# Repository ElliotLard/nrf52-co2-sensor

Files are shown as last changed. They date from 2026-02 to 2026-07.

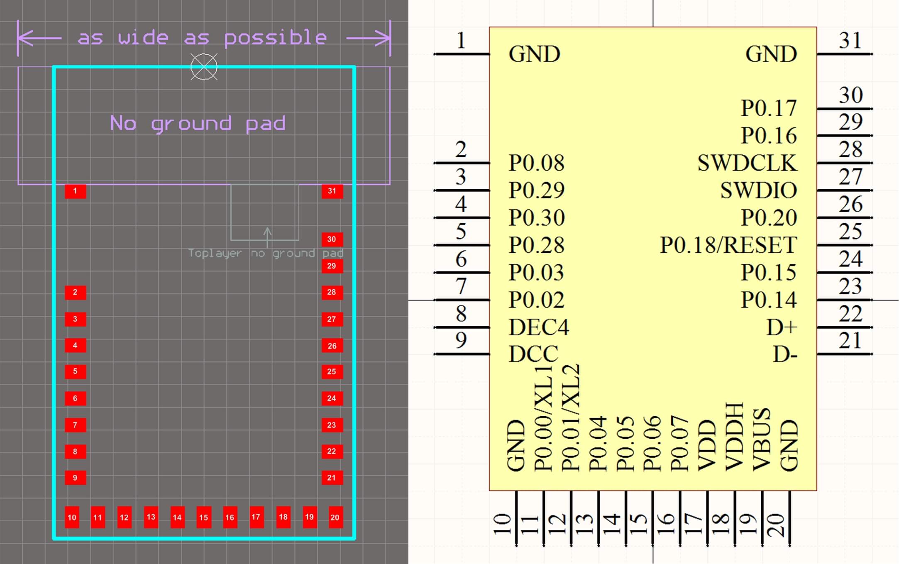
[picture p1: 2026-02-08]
hardware/datasheets/MDBT50 & MDBT50-P Footprint & Design Guide (221129)/Footprint (nRF52820)_MDBT50-256R & P256R/MDBT50 Altium Library/MDBT50_52820 Altium Library-210706.jpg

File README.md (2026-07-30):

# nrf52-co2-sensor





BLE-based smart home compatible CO₂ sensor built around the **nRF52840 (via MDBT50Q module)** and the **Sensirion SCD30 NDIR CO₂ sensor**.

The device measures indoor CO₂ concentration and transmits readings wirelessly using **Bluetooth Low Energy (BLE)** for integration with smart home systems or mobile applications.

This project includes:

- Custom **schematic design**
- **PCB layout** in KiCad
- **BLE communication**
- Sensor integration using **I²C**

---

# Project Status

**Current Status (30 July 2026)**
- Rev A Board has been printed and assembled
---
#Front


#Back


# Hardware Design

## Schematic (Rev A)



## PCB Layout (Rev A)



---

# Design Goals

- Accurate CO₂ measurement
- Wireless communication via **Bluetooth Low Energy**
- USB-C powered device
- Smart home compatibility

---

# Major Components

## MCU + BLE

**MDBT50Q-1MV2**  
Contains **Nordic nRF52840 BLE microcontroller**



---

## CO₂ Sensor

**Sensirion SCD30**

NDIR-based CO₂ sensor with integrated temperature and humidity measurement.



---

## USB-C Receptacle

**USB4105-GF-A**

Used for power and optional USB communication/debugging.



---

<!---
Future updates:

- Rev B schematic
- PCB layout screenshots
- Fabricated board photos

---
-->
# Firmware

*(Placeholder — firmware development will begin after PCB assembly)*

Planned features:

- I²C communication with SCD30
- CO₂ measurement acquisition
- BLE data transmission
- Low power operation

---

# Tools Used

- **KiCad** — schematic and PCB design
- **Git / GitHub** — version control
- **Datasheets and reference designs** from component manufacturers

---

# Future Work

- BLE data integration with **Home Assistant**
- Explore possibility of Battery-powered variant
- Compact enclosure design
- Airflow optimization for accurate sensing

---

<!---
# License

*(Placeholder — consider adding MIT or Apache license)*
-->

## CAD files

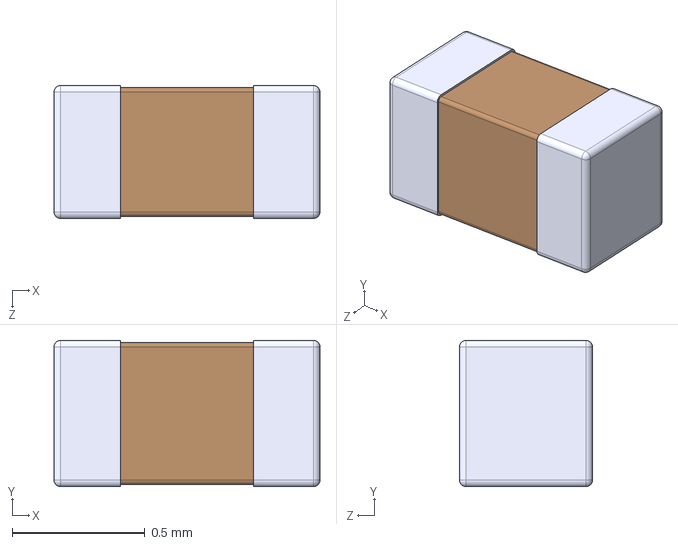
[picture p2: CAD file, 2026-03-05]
hardware/BLM15AX601SN1D (Ferrite Bead)/BEADC1005X55N.step
1.00 x 0.55 x 0.5 mm

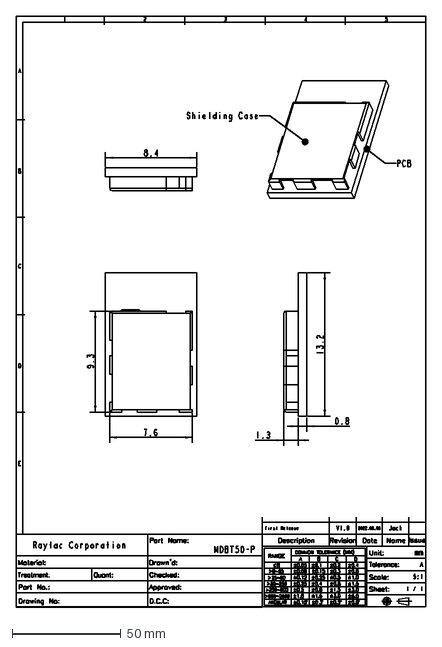
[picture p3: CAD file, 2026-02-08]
hardware/datasheets/MDBT50 & MDBT50-P Footprint & Design Guide (221129)/2D & 3D Drawing/MDBT50-P/2D/MDBT50-P 2D Drawing_20221129.dxf
188.5 x 271.9 mm

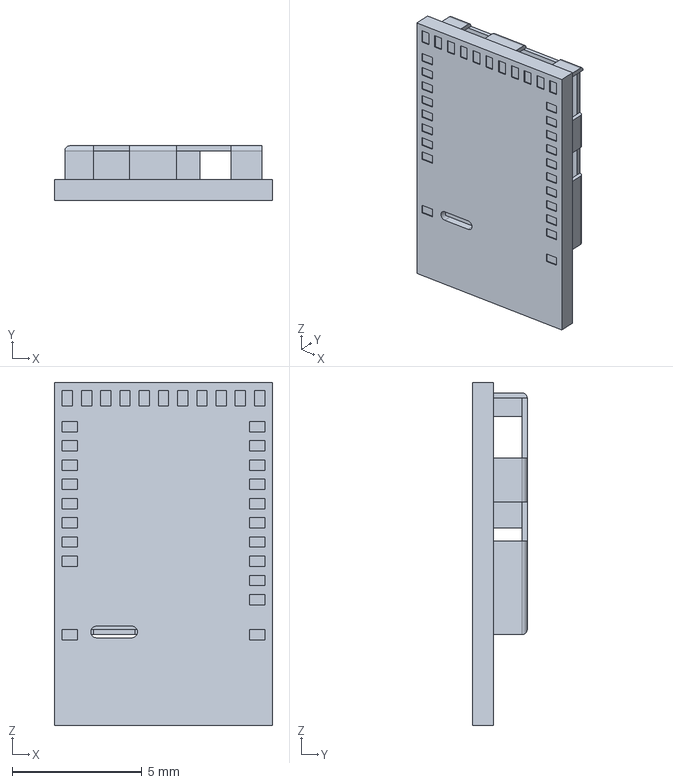
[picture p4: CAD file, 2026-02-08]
hardware/datasheets/MDBT50 & MDBT50-P Footprint & Design Guide (221129)/2D & 3D Drawing/MDBT50-P/3D/MDBT50-P_220606.stp
8.40 x 2.10 x 13.2 mm

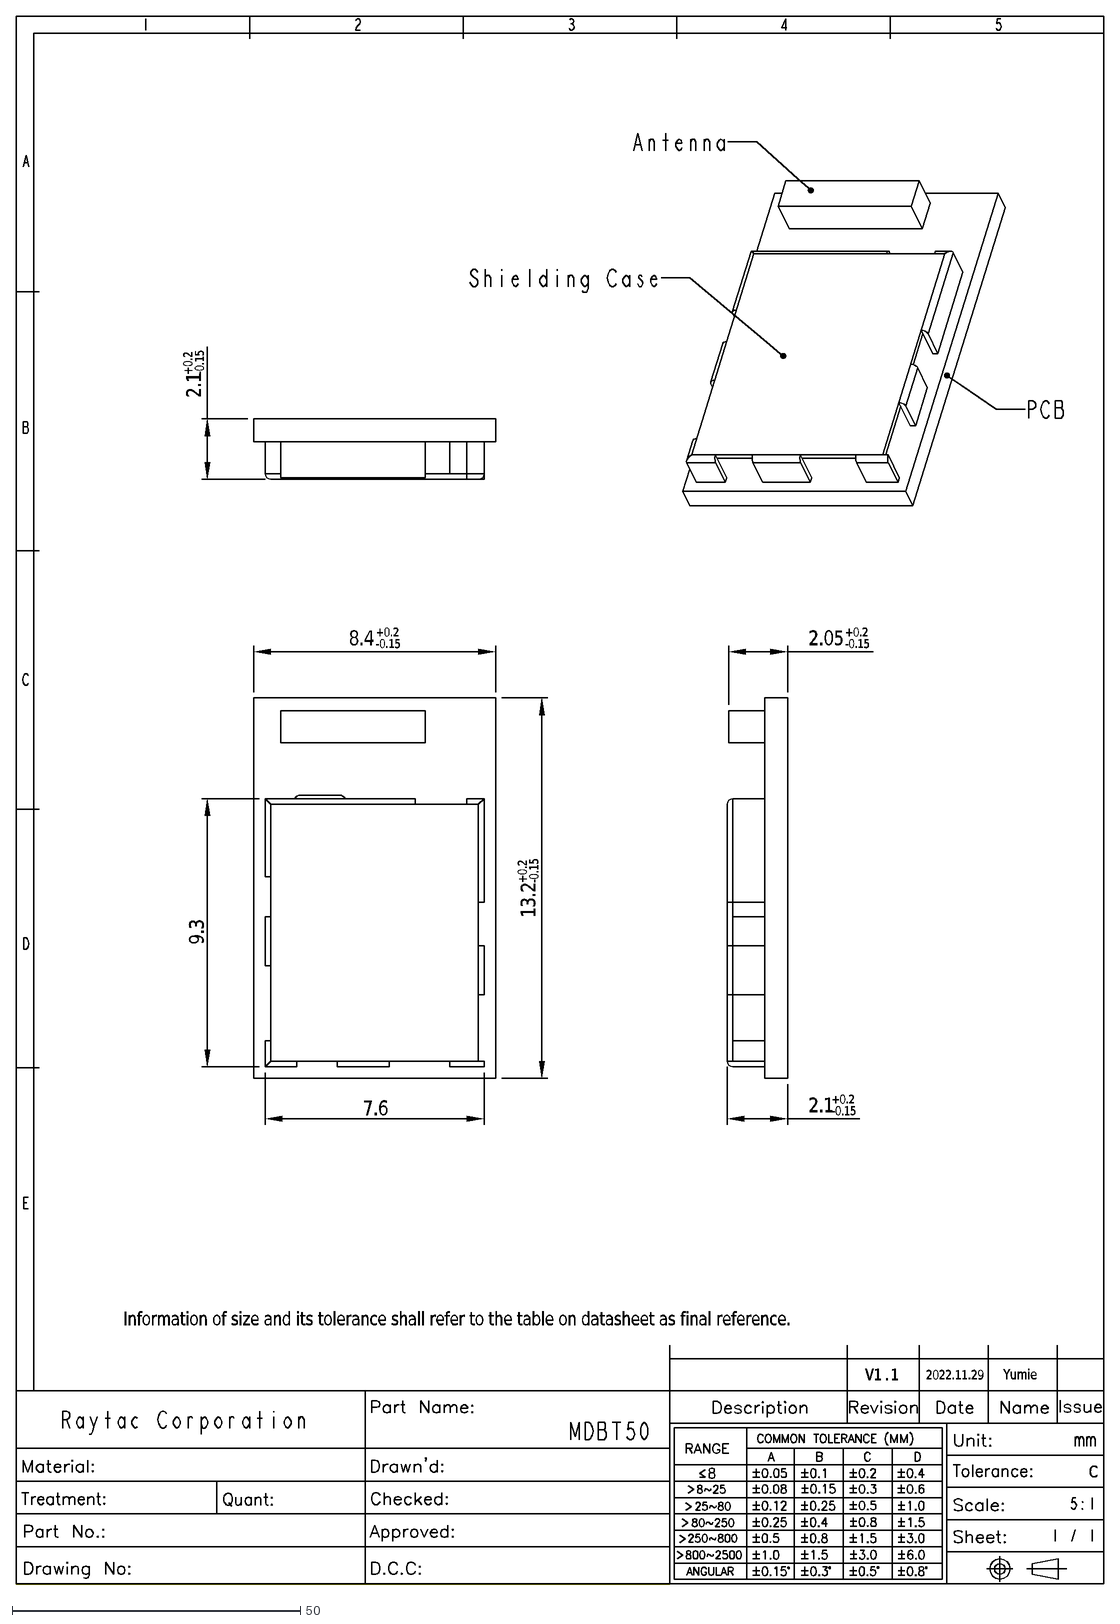
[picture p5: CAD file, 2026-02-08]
hardware/datasheets/MDBT50 & MDBT50-P Footprint & Design Guide (221129)/2D & 3D Drawing/MDBT50/2D/MDBT50 2D Drawing_20221129.dxf
9.3
7.6
8.4
+0.2
-0.15
13.2
2.1
2.05
2022.11.29
Yumie
V1
.
1
C
Information of size and its tolerance shall refer to the table on datasheet as final reference.

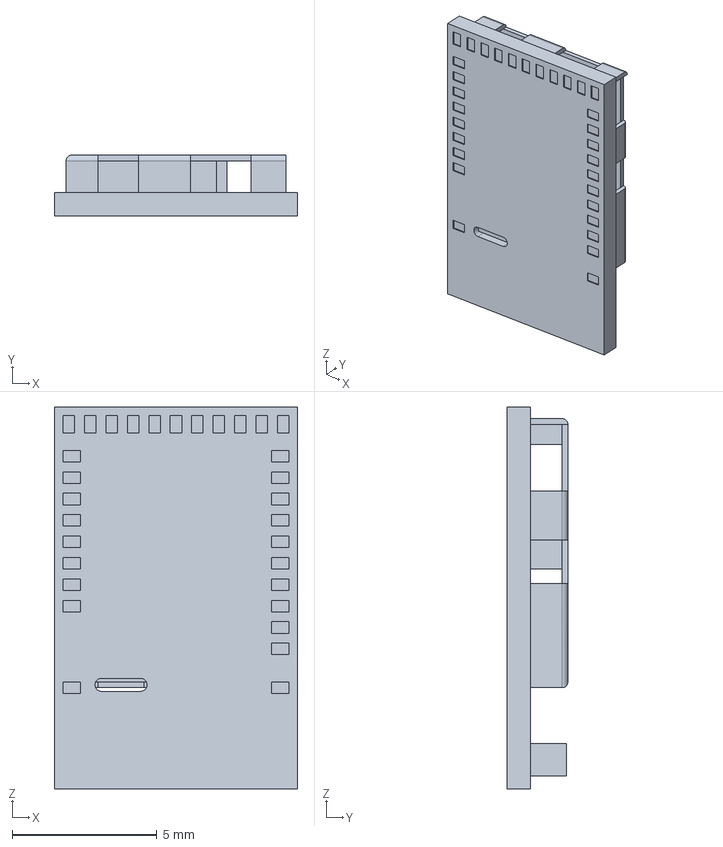
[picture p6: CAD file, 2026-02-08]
hardware/datasheets/MDBT50 & MDBT50-P Footprint & Design Guide (221129)/2D & 3D Drawing/MDBT50/3D/MDBT50.stp
8.40 x 2.10 x 13.2 mm

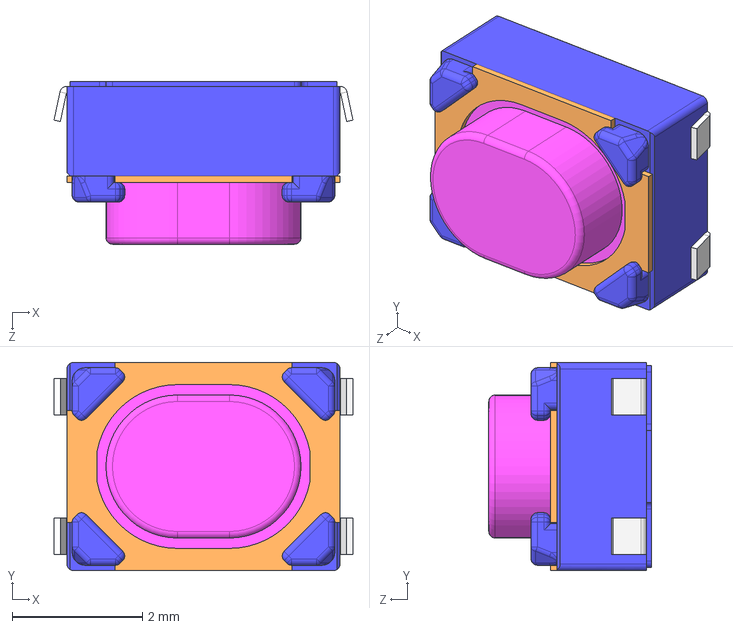
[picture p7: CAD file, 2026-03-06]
hardware/Kicad Imports/SKRPAB.STEP
4.60 x 3.20 x 2.50 mm

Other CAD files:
hardware/datasheets/MDBT50 & MDBT50-P Footprint & Design Guide (221129)/2D & 3D Drawing/MDBT50-P/2D/MDBT50-P 2D Drawing_20221129.dwg
hardware/datasheets/MDBT50 & MDBT50-P Footprint & Design Guide (221129)/2D & 3D Drawing/MDBT50-P/3D/MDBT50-P_220606.igs
hardware/datasheets/MDBT50 & MDBT50-P Footprint & Design Guide (221129)/2D & 3D Drawing/MDBT50/2D/MDBT50 2D Drawing_20221129.dwg
hardware/datasheets/MDBT50 & MDBT50-P Footprint & Design Guide (221129)/2D & 3D Drawing/MDBT50/3D/MDBT50.igs

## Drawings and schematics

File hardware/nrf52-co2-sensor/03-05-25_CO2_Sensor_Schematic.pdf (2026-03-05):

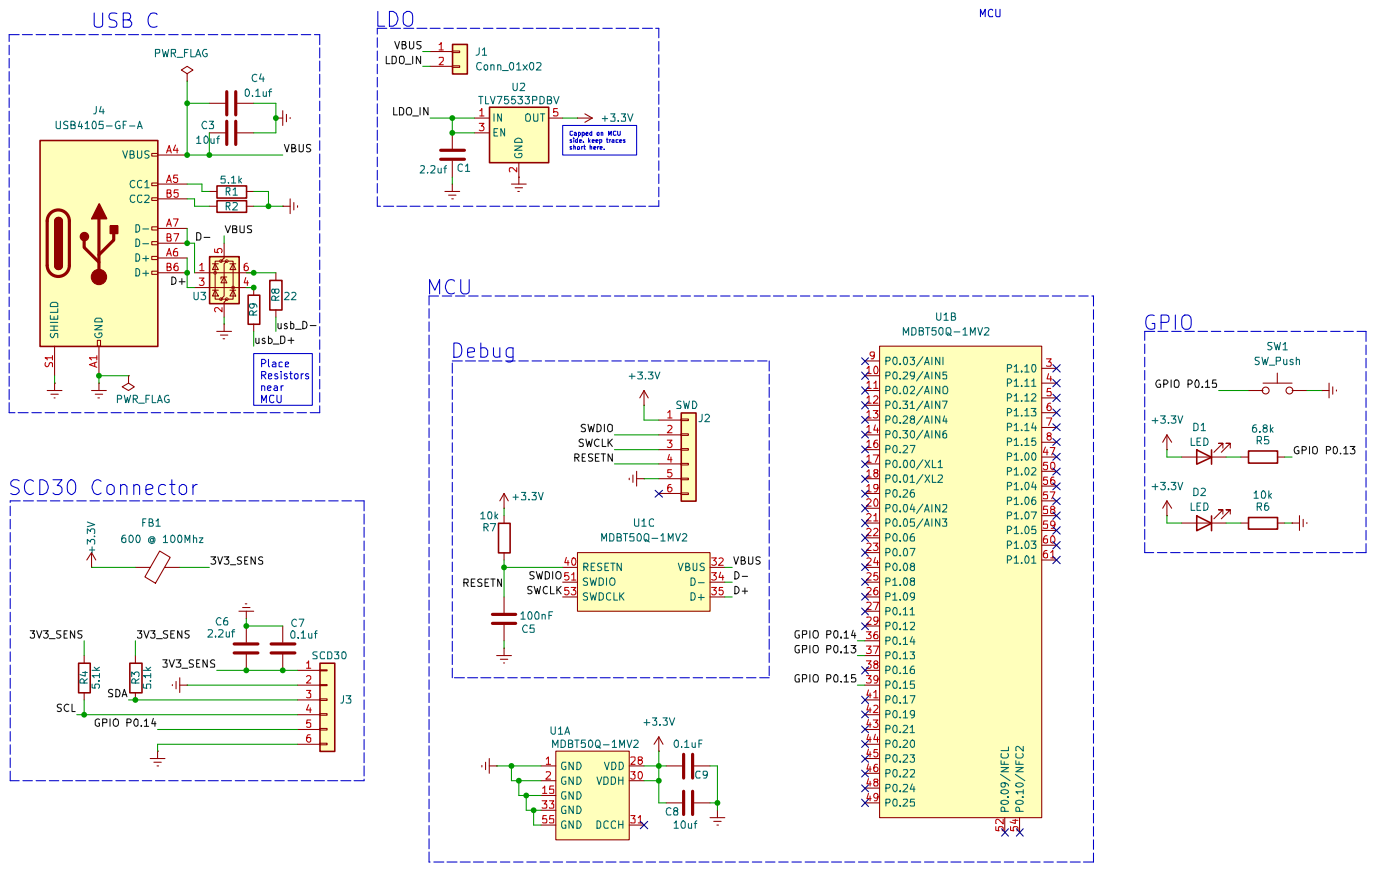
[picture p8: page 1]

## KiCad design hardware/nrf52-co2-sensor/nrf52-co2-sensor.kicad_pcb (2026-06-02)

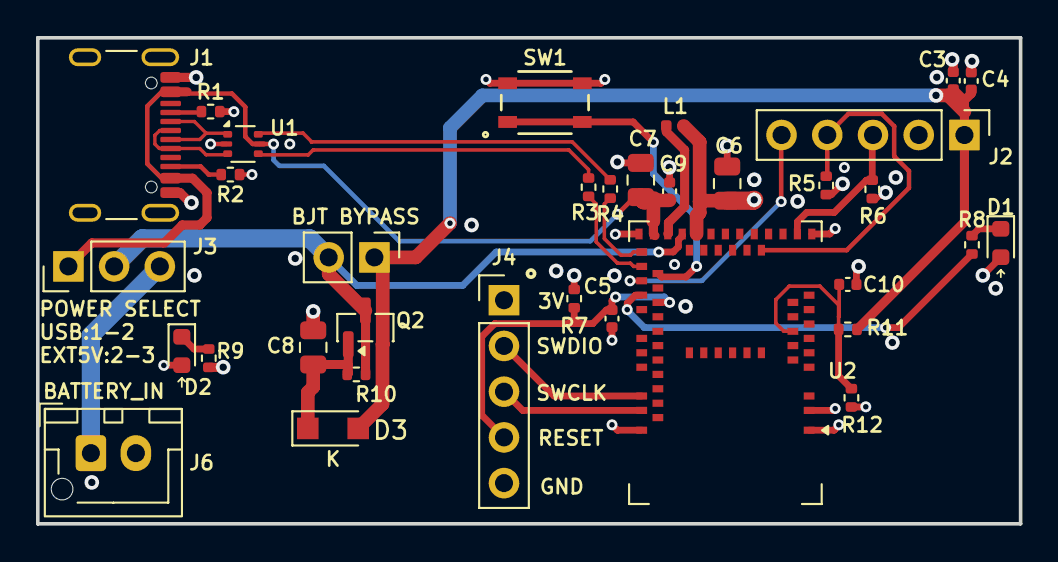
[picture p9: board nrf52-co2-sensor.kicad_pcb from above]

Board: 4 copper layers, 54.6 x 27.0 mm, 34 parts (0 on the bottom side), 27 nets.

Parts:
C3: 2.2uf; C_0402_1005Metric
C4, C9: 0.1uf; C_0402_1005Metric
C5: 100nF; C_0402_1005Metric
C6, C7: 10uf; C_0805_2012Metric
C8: 47uf; C_0805_2012Metric
C10: 10nf; C_0402_1005Metric
D1, D2: LED; LED_0603_1608Metric
D3: 1N914; Nexperia_CFP3_SOD-123W
J1: USB4105-GF-A; USB_C_Receptacle_GCT_USB4105-xx-A_16P_TopMnt_Horizontal
J2: SCD30; PinHeader_1x05_P2.54mm_Vertical
J3: Conn_01x03; PinHeader_1x03_P2.54mm_Vertical
J4: SWD; PinHeader_1x05_P2.54mm_Vertical
J6: Conn_01x02; JST_XH_B2B-XH-AM_1x02_P2.50mm_Vertical
J7: Conn_01x02; PinHeader_1x02_P2.54mm_Vertical
L1: 10uH; L_0402_1005Metric
Q2: Q_NPN_BEC; SOT-23
R1, R2: 5.1k; R_0402_1005Metric
R3, R4: 22; R_0402_1005Metric
R5, R6, R9: 4.7k; R_0402_1005Metric
R7: 10k; R_0402_1005Metric
R8: 2.2k; R_0402_1005Metric
R10: 150; R_0402_1005Metric
R11: 2.2M; R_0402_1005Metric
R12: 1M; R_0402_1005Metric
SW1: SW_Push; SW4_SKRPABE010_ALPS
U1: USBLC6-2P6; SOT-666
U2: MDBT50Q-1MV2; Raytac_MDBT50Q

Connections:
/3V_VDD: C6.2, D1.2 (A), D2.2 (A), J4.1, L1.1, R5.2, R6.2, R7.2, U2.28 (VDD)
/BASE: C8.2, D3.1 (K), Q2.1 (B), R10.1
/BUTTON_1: SW1.1, SW1.2, U2.36 (P0.14)
/CC1: J1.A5 (CC1), R1.1
/CC2: J1.B5 (CC2), R2.1
/D1+: R3.2, U1.4 (I/O2)
/D1-: R4.1, U1.6 (I/O1)
/D+: J1.A6 (D+), J1.B6 (D+), U1.3 (I/O2)
/D-: J1.A7 (D-), J1.B7 (D-), U1.1 (I/O1)
/DCCH: L1.2, U2.31 (DCCH)
/D_MCU+: R3.1, U2.35 (D+)
/D_MCU-: R4.2, U2.34 (D-)
/External Power: J3.3, J6.1
/LED_1: R8.2, U2.39 (P0.15)
/POWER_ADC: C10.2, R11.2, R12.1, U2.9 (P0.03/AINI)
/POWER_RAW: J3.2, J7.2, Q2.3 (C), R10.2, U2.30 (VDDH)
/POWER_SENS: C3.1, C4.1, D3.2 (A), J2.1, J7.1, Q2.2 (E), R11.1
/RESETN: C5.2, J4.4, R7.1, U2.40 (RESETN)
/SCD30_RDY: J2.5, U2.37 (P0.13)
/SCD30_SCL: J2.3, R6.1, U2.16 (P0.27)
/SCD30_SDA: J2.4, R5.1, U2.19 (P0.26)
/SWCLK: J4.3, U2.53 (SWDCLK)
/SWDIO: J4.2, U2.51 (SWDIO)
/VBUS: C7.2, C9.1, J1.A4 (VBUS), J1.A9 (VBUS), J1.B4 (VBUS), J1.B9 (VBUS), J3.1, U1.5 (VBUS), U2.32 (VBUS)
GND: C3.2, C4.2, C5.1, C6.1, C7.1, C8.1, C9.2, C10.1, J1.A1 (GND), J1.A12 (GND), J1.B1 (GND), J1.B12 (GND), J2.2, J4.5, J6.2, R1.2, R2.2, R9.2, R12.2, SW1.3, SW1.4, U1.2 (GND), U2.1 (GND), U2.2 (GND), U2.15 (GND), U2.33 (GND), U2.55 (GND)
unnamed: D1.1 (K), R8.1
unnamed: D2.1 (K), R9.1

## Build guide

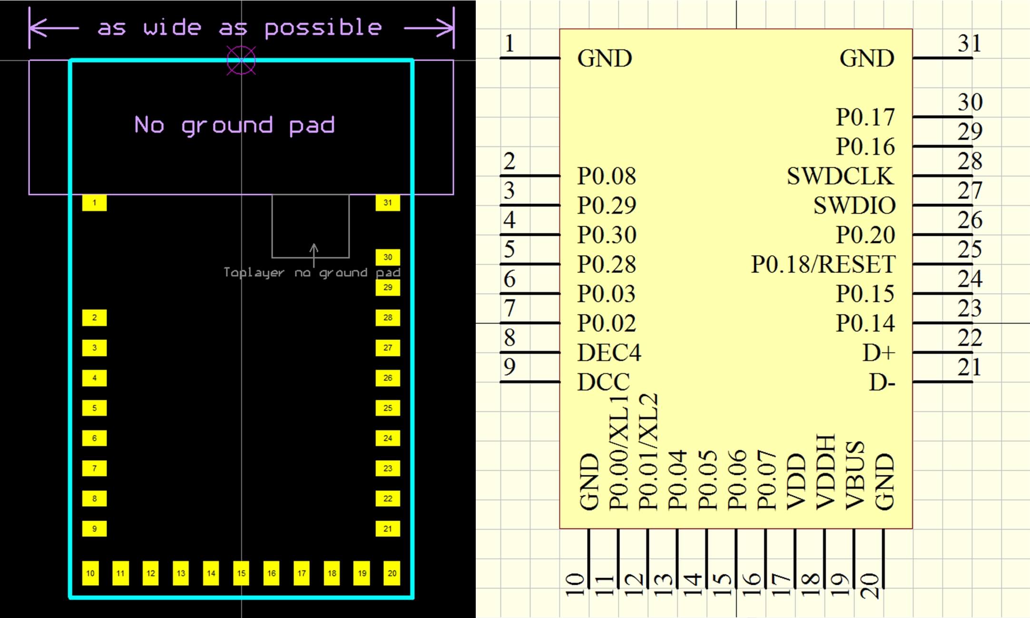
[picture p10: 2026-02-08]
hardware/datasheets/MDBT50 & MDBT50-P Footprint & Design Guide (221129)/Footprint (nRF52820)_MDBT50-256R & P256R/MDBT50 Protel Library/MDBT50_52820 Protel Library-210706.jpg

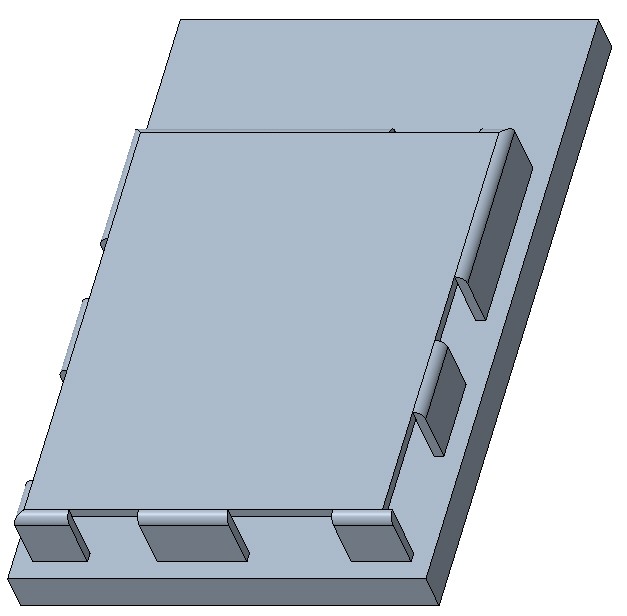
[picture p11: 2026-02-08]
hardware/datasheets/MDBT50 & MDBT50-P Footprint & Design Guide (221129)/2D & 3D Drawing/MDBT50-P/3D/MDBT50-P-1.jpg

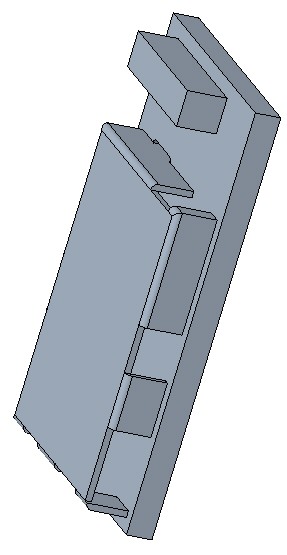
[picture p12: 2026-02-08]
hardware/datasheets/MDBT50 & MDBT50-P Footprint & Design Guide (221129)/2D & 3D Drawing/MDBT50/3D/MDBT50-4.jpg

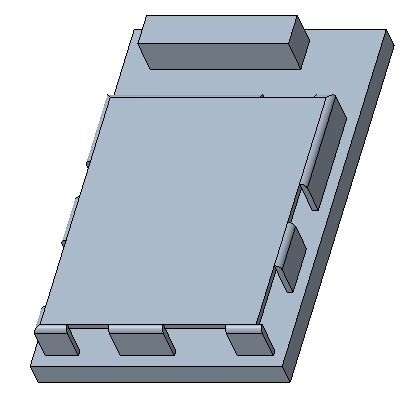
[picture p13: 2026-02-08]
hardware/datasheets/MDBT50 & MDBT50-P Footprint & Design Guide (221129)/2D & 3D Drawing/MDBT50/3D/MDBT50-1.jpg

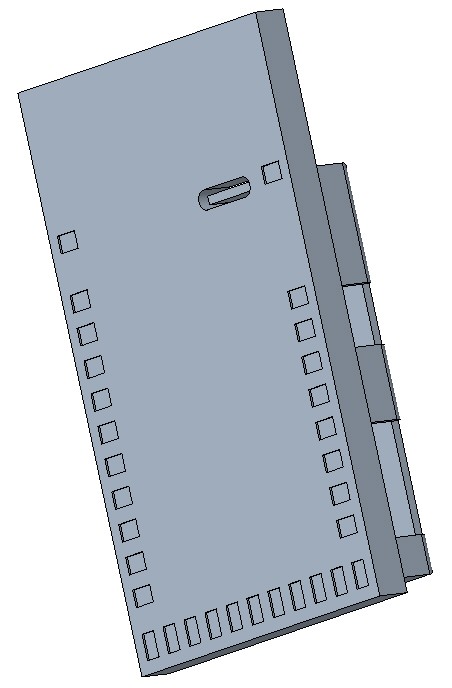
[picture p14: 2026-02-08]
hardware/datasheets/MDBT50 & MDBT50-P Footprint & Design Guide (221129)/2D & 3D Drawing/MDBT50-P/3D/MDBT50-P-3.jpg

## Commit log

2026-02-08 added datasheet, start of kicad project
    [MDBT50 2D Drawing_20221129.dwg, MDBT50 2D Drawing_20221129.dxf, MDBT50-P 2D Drawing_20221129.dwg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]
2026-02-15 Finished revision 1 of schematic passed ERC and ready for review
2026-02-16 changed one of the LED's to always-on and increased resistor values for both LED's to 10k for always-on and 6.8k for GPIO
2026-02-16 Added 0.1uF decoupling on VDD, last commit before PCB Layout
2026-02-18 Removed external pullups on I2C, decided they were unnecessary for 100khz with the internals. Also removed redundant caps on the side of LOD, but left the ones on the side of the MCU.
2026-03-02 changed usb-c component and rewired with an ESD diode. Also started choosing other components and footprints.
2026-03-02 added external pullups back in for i2c
2026-03-05 finished assigning footprints, chose LEDs and button, assigned 4.7k resistors to I2C pullups and also to LED's. Passed ERC, usb_D- and + were not connected properly and fixed that as well
    [BEADC1005X55N.step]
2026-03-06 Started preliminary pcb component placement. Switched JST for header. also switched pushbutton component for a smaller footprint.
    [SKRPAB.STEP, nrf52-co2-sensor.kicad_pcb]
2026-03-07 Last commit before power rework
    [nrf52-co2-sensor.kicad_pcb]
2026-03-07 reworked power to remove LDO and work directly from USB
2026-03-07 fix folder structure
    [SKRPAB.STEP]
2026-03-09 first iteration of pcb layout ready for review
    [nrf52-co2-sensor.kicad_pcb]
2026-03-09 Update README.md
    Updated readme with current project status
2026-06-01 Changes made to schematic. BJT Lowpass filter, jumper for power measurement/choosing battery vs usb power, removal of redundant capacitors, and other additional fixes.
    [nrf52-co2-sensor.kicad_sch]
2026-06-02 Finished PCB Layout and BOM read for review
    [nrf52-co2-sensor.kicad_pcb, nrf52-co2-sensor.kicad_sch]
2026-07-30 Revise README with current project status
    Updated project status and removed outdated information.
